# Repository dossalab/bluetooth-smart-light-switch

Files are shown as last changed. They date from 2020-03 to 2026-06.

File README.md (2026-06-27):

# Bluetooth controlled cord light switch

**Before building, read this carefully (especially Safety guidelines)**

This project aims to create a remote-controlled, *smart* cord light switch. It has both physical control button and Bluetooth LE capabilities, allowing for a very natural user experience.

This repo contains both PCB design and firmware.

Hardware seems to work, but has barely been tested in the field. The high voltage part is rated at 220-230V / 50 Hz (European-ish standard). It should be trivial to recalculate the supply for the US standard.

The firmware was never fully developed, but `firmware` directory contains the current work-in-progress state to get you started.

**Make sure you know what you're doing. This project involves working with high voltages and requires advanced electronics experience. I'm not taking any responsibility for any damage arising from use of this device**

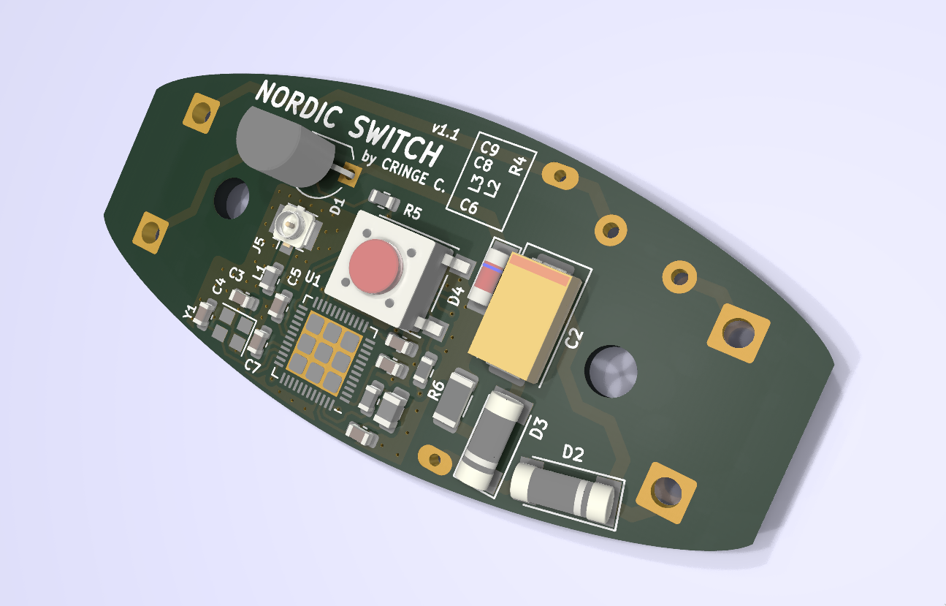
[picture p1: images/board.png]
board render


## Bringup

There are 4 solder pads underneath the board. You'll have to solder some wires to them in order to connect to the programming probe. Supply your own safe external power from your debugging probe or any other low-power source. **NEVER INTERFACE WITH THE DEVICE WHILE PLUGGED INTO MAINS POWER!**

The firmware is written in Rust and uses Embassy, the async framework with nrf-softdevice crate for BLE.

## Some safety guidelines

- Never touch any parts of the board while operational - you'd likely get a shock;
- Don't leave the device unattended for now - it's not stable enough to trust;
- Be in a good state of mind and pay attention to what you are doing - **it is easy to make mistakes and burn your stuff**

## Roadmap

- Proper case design (I just used one from the real switch, with drilled-out insides);
- HomeAssistant integration.

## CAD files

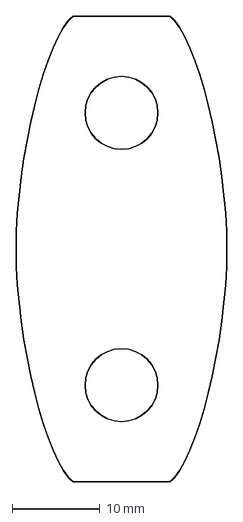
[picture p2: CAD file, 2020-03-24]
board/case-board-outline.dxf
24.0 x 53.0 mm

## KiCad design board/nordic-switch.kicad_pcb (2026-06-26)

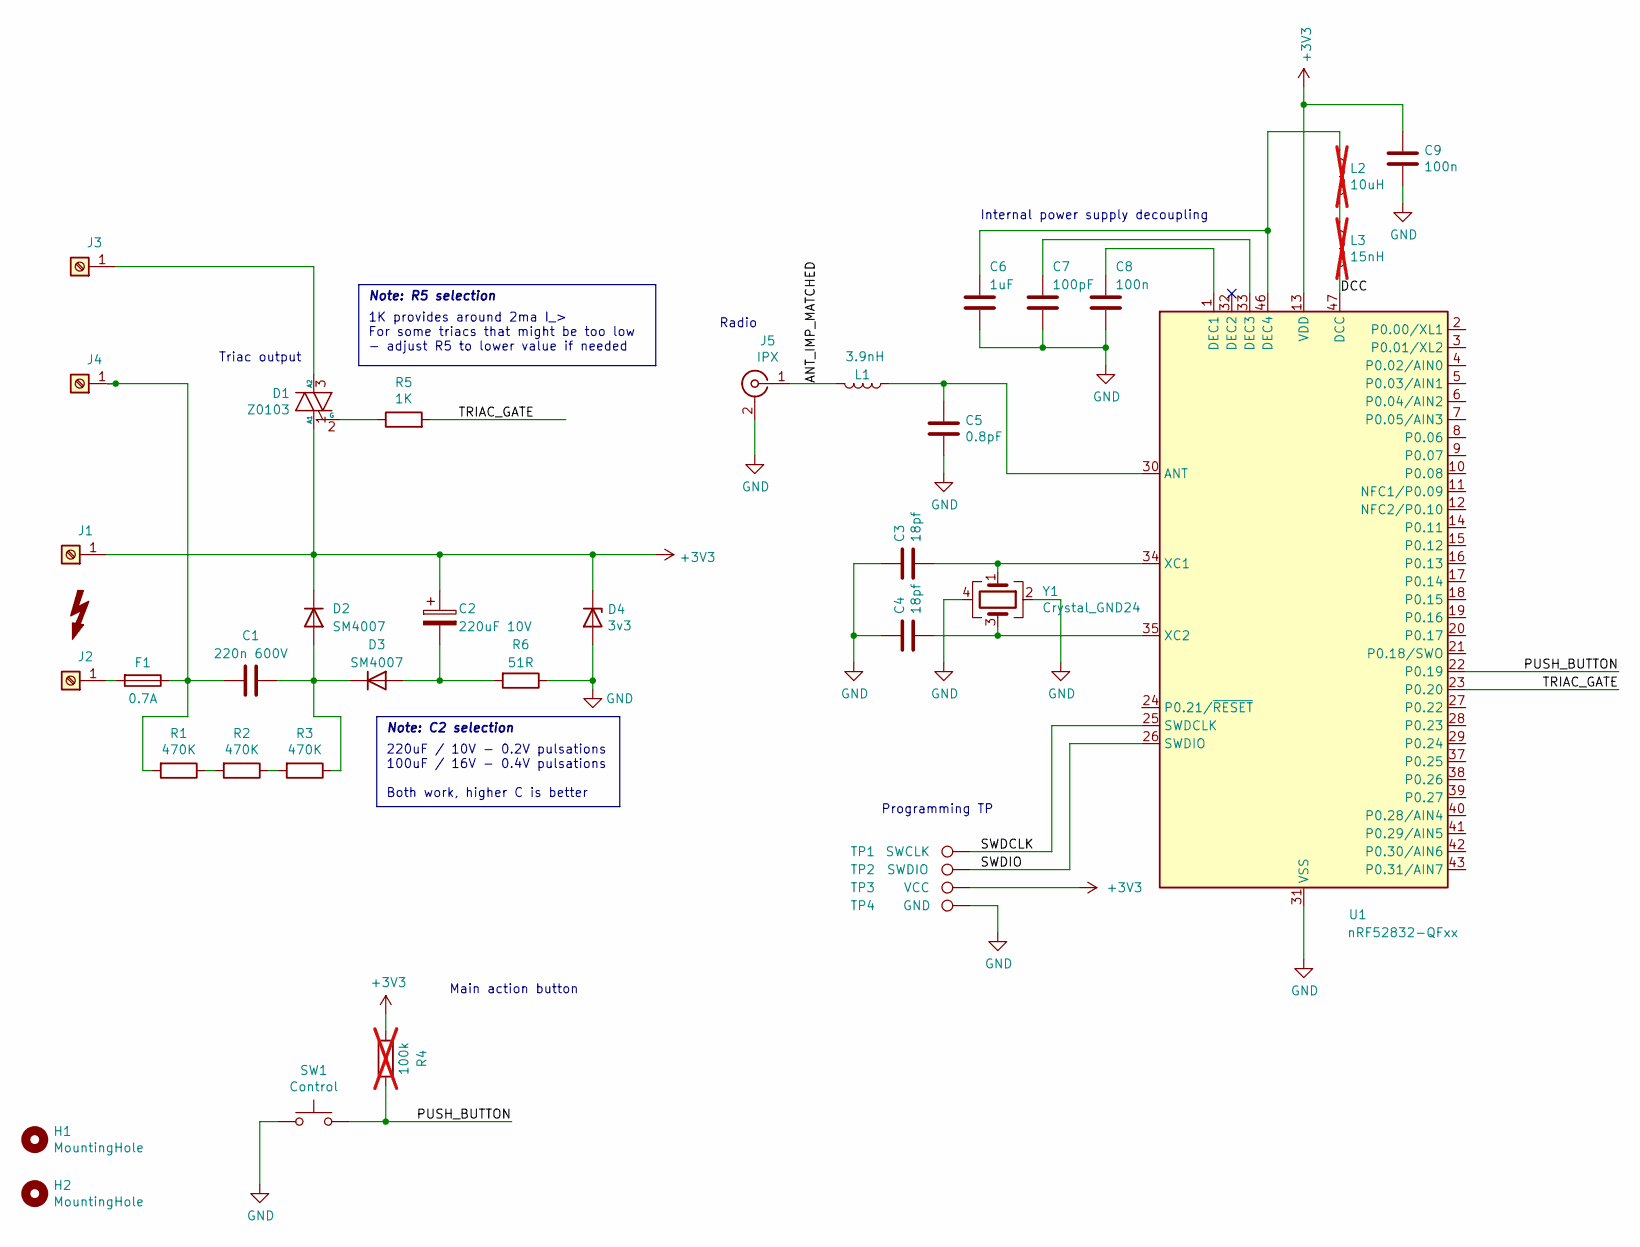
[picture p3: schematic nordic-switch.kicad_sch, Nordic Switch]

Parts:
C1: 220n 600V; CP_CBB_684J_400V_Flat
C2: 220uF 10V; CP_EIA-7343-30_AVX-N
C3, C4: 18pf; C_0603_1608Metric
C5: 0.8pF; C_0603_1608Metric
C6: 1uF; C_0603_1608Metric
C7: 100pF; C_0603_1608Metric
C8, C9: 100n; C_0603_1608Metric
D1: Z0103; TO-92_Inline_Wide
D2, D3: SM4007; D_MELF
D4: 3v3; D_MiniMELF
F1: 0.7A; Fuse_Littelfuse_395Series
H1, H2: MountingHole; MountingHole_3.2mm_M3
J1, J2, J3, J4: Screw_Terminal_01x01; SolderWire-1sqmm_1x01_D1.4mm_OD2.7mm
J5: IPX; U.FL_Hirose_U.FL-R-SMT-1_Vertical
L1: 3.9nH; L_0603_1608Metric
L2: 10uH; L_0805_2012Metric; not fitted
L3: 15nH; L_0603_1608Metric; not fitted
R1, R2, R3: 470K; R_1206_3216Metric
R4: 100k; R_0603_1608Metric; not fitted
R5: 1K; R_0603_1608Metric
R6: 51R; R_1206_3216Metric
SW1: Control; SW_SPST_PTS645
TP1: SWCLK; TestPoint_Pad_D1.0mm
TP2: SWDIO; TestPoint_Pad_D1.0mm
TP3: VCC; TestPoint_Pad_D1.0mm
TP4: GND; TestPoint_Pad_D1.0mm
U1: nRF52832-QFxx; QFN-48-1EP_6x6mm_P0.4mm_EP4.6x4.6mm
Y1: Crystal_GND24; Crystal_SMD_2520-4Pin_2.5x2.0mm

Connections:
+3V3: C2.1, C9.1, D1.1 (A1), D2.1 (K), D4.1 (K), J1.1, R4.2, TP3.1, U1.13 (VDD), U1.36 (VDD), U1.48 (VDD)
/ANT_IMP_MATCHED: J5.1 (In), L1.2
/DCC: L3.2, U1.47 (DCC)
/PUSH_BUTTON: R4.1, SW1.2, U1.22 (P0.19)
/SWDCLK: TP1.1, U1.25 (SWDCLK)
/SWDIO: TP2.1, U1.26 (SWDIO)
/TRIAC_GATE: R5.2, U1.23 (P0.20)
GND: C3.1, C4.1, C5.2, C6.2, C7.2, C8.2, C9.2, D4.2 (A), J5.2 (Ext), R6.1, SW1.1, TP4.1, U1.31 (VSS), U1.45 (VSS), U1.49 (VSS), Y1.2, Y1.4
unnamed: D1.3 (A2), J3.1
unnamed: D1.2 (G), R5.1
unnamed: C1.2, D2.2 (A), D3.1 (K), R3.1
unnamed: C2.2, D3.2 (A), R6.2
unnamed: F1.2, J2.1
unnamed: C1.1, F1.1, J4.1, R1.2
unnamed: L2.2, L3.1
unnamed: R1.1, R2.2
unnamed: R2.1, R3.2
unnamed: C5.1, L1.1, U1.30 (ANT)
unnamed: C8.1, U1.1 (DEC1)
unnamed: C7.1, U1.33 (DEC3)
unnamed: C6.1, L2.1, U1.46 (DEC4)
unnamed: C3.2, U1.34 (XC1), Y1.1
unnamed: C4.2, U1.35 (XC2), Y1.3

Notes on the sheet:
Triac output
Programming TP
Internal power supply decoupling
1K provides around 2ma I_{gt} For some triacs that might be too low - adjust R5 to lower value if needed
Main action button
Note: R5 selection
Note: C2 selection
Radio
220uF / 10V - 0.2V pulsations 100uF / 16V - 0.4V pulsations Both work, higher C is better

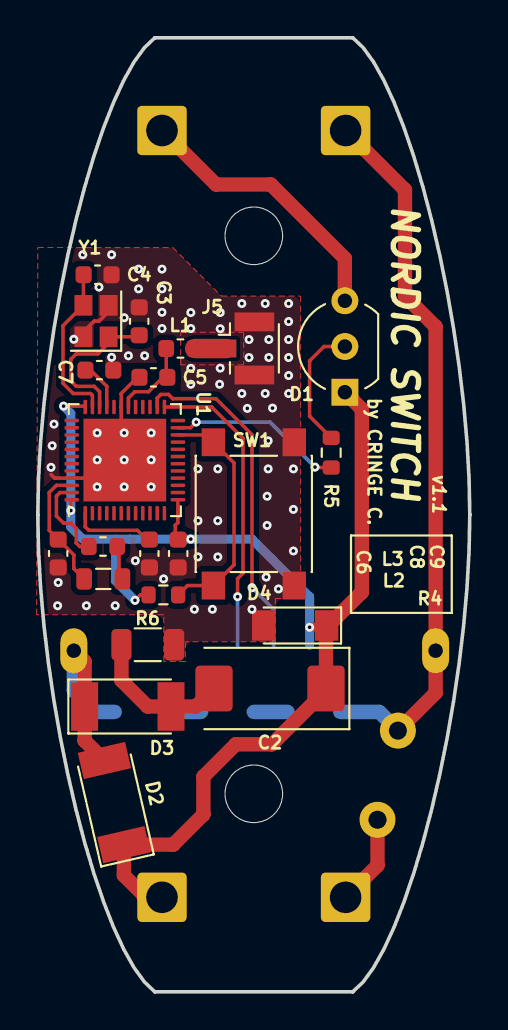
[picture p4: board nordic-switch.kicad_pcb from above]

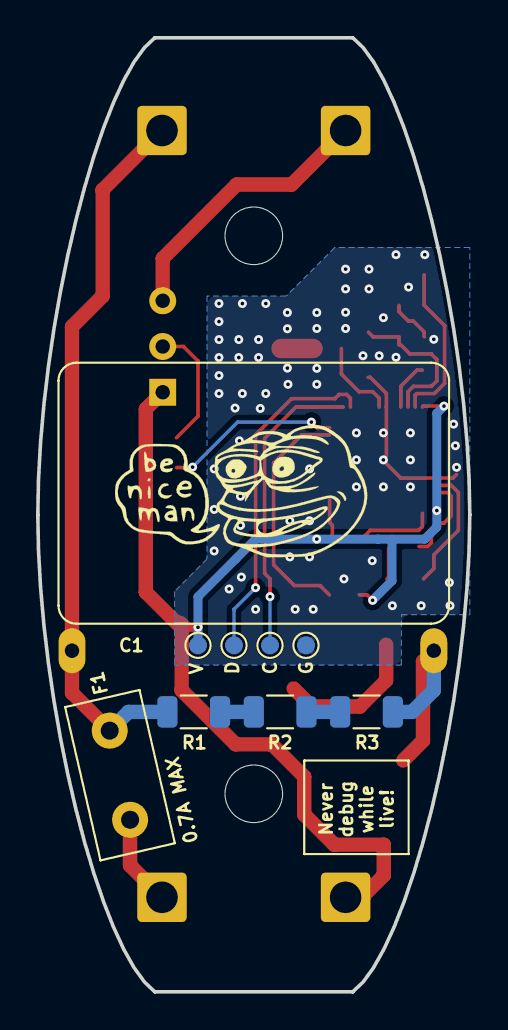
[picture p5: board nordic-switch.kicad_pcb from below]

Board: 2 copper layers, 24.0 x 53.0 mm, 37 parts (9 on the bottom side), 23 nets.

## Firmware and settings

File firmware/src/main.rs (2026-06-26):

//! A part of Nordic switch - Bluetooth controlled cord light switch project
//! This firmware and hardware is a work in progress - use at your own risk.

#![no_std]
#![no_main]

use assign_resources::assign_resources;
use defmt::{info, unwrap};
use embassy_nrf::peripherals;
use embassy_sync::{blocking_mutex::raw::CriticalSectionRawMutex, signal::Signal};
use embassy_time::Timer;
use futures::future;
use git_version::git_version;
use heapless::String;

use embassy_nrf::{
    gpio::{self, Input},
    interrupt, Peripherals,
};
use nrf_softdevice::{
    ble::{self, advertisement_builder as advb, peripheral as blep},
    raw as nrf_defines, Softdevice,
};

use defmt_rtt as _;
use panic_probe as _;

// There are only 2 'resources' - still, good for consistency across projects :)
assign_resources! {
    button: ButtonResources {
        pin: P0_19,
    },
    triac: TriacResources {
        pin: P0_20,
    }
}

/// Actions used for triac control channel
#[derive(defmt::Format)]
enum TriacAction {
    On,
    Off,
    Toggle,
}

/// Channel used to send messages to triac
type TriacSignal = Signal<CriticalSectionRawMutex, TriacAction>;

/// Gatt configuration. A single 'custom' control service containing everything needed.
#[nrf_softdevice::gatt_service(uuid = "c831c2f2-817f-11ee-b962-0242ac120002")]
pub struct ControlService {
    /// Control point that controls the lamp
    #[characteristic(uuid = "c831c2f2-817f-11ee-b962-0242ac130002", read, write)]
    triac_control: bool,

    /// Version string of this firmware for debugging
    #[characteristic(uuid = "c831c2f2-817f-11ee-b962-0242ac140002", read)]
    version: String<32>,
}

/// A gatt server that holds all of our characteristics
#[nrf_softdevice::gatt_server]
pub struct GattServer {
    control: ControlService,
}

/// Runs advertisement cycle. Returns connection that we can feed to the gatt_server.
async fn advertise(softdevice: &Softdevice) -> Result<ble::Connection, blep::AdvertiseError> {
    static ADV_DATA: advb::LegacyAdvertisementPayload = advb::LegacyAdvertisementBuilder::new()
        .flags(&[advb::Flag::GeneralDiscovery, advb::Flag::LE_Only])
        .full_name("Nordic Switch")
        .build();

    static SCAN_DATA: advb::LegacyAdvertisementPayload =
        advb::LegacyAdvertisementBuilder::new().build();

    let packet = blep::ConnectableAdvertisement::ScannableUndirected {
        adv_data: &ADV_DATA,
        scan_data: &SCAN_DATA,
    };

    let config = blep::Config {
        interval: 1600, // 1s
        ..Default::default()
    };

    blep::advertise_connectable(softdevice, packet, &config).await
}

/// Task that handles all the bluetooth stuff
#[embassy_executor::task]
async fn bluetooth_task_run(softdevice: &'static mut Softdevice, triac: &'static TriacSignal) {
    let gatt = unwrap!(GattServer::new(softdevice));

    // Store the git version in the control service to help debug issues in the field
    unwrap!(gatt
        .control
        .version_set(&unwrap!(git_version!().try_into())));

    // That's how we handle all events coming from the gatt_server
    let event_handler = |e: GattServerEvent| match e {
        GattServerEvent::Control(event) => match event {
            ControlServiceEvent::TriacControlWrite(on) => triac.signal(if on {
                TriacAction::On
            } else {
                TriacAction::Off
            }),
        },
    };

    future::join(
        // Run connection cycle
        async {
            loop {
                if let Ok(connection) = advertise(softdevice).await {
                    ble::gatt_server::run(&connection, &gatt, event_handler).await;
                }
            }
        },
        // Run softdevice logic
        softdevice.run(),
    )
    .await;
}

/// Task that listens for triac signals and reacts appropriately
#[embassy_executor::task]
async fn triac_controller_run(res: TriacResources, signal: &'static TriacSignal) {
    // note logic level inversion here - we start with high level
    let mut triac = gpio::Output::new(res.pin, gpio::Level::High, gpio::OutputDrive::Standard);

    loop {
        let action = signal.wait().await;
        info!("received triac action '{}'", action);
        match action {
            TriacAction::On => triac.set_low(),
            TriacAction::Off => triac.set_high(),
            TriacAction::Toggle => triac.toggle(),
        }
    }
}

/// Task that handles button events and sends actions to triac task
#[embassy_executor::task]
async fn button_listener_run(res: ButtonResources, triac: &'static TriacSignal) {
    let mut button = Input::new(res.pin, gpio::Pull::Up);

    loop {
        button.wait_for_falling_edge().await;

        // do a second probe for debouncing
        Timer::after_millis(10).await;
        if button.is_low() {
            triac.signal(TriacAction::Toggle);
        }

        Timer::after_millis(20).await;
    }
}

/// Initializes embassy for NRF52.
fn init_embassy() -> Peripherals {
    let mut config = embassy_nrf::config::Config::default();

    // Softdevice implicitly utilizes the highest-level interrupt priority
    // We have to move all other interrupts to lower priority, unless
    // random issues and asserts from the Softdevice may (and will) occur

    config.gpiote_interrupt_priority = interrupt::Priority::P2;
    config.time_interrupt_priority = interrupt::Priority::P2;

    embassy_nrf::init(config)
}

/// Initializes SoftDevice
fn init_softdevice() -> &'static mut Softdevice {
    let config = nrf_softdevice::Config {
        // The board is lacking LF crystal because of the space restrictions.
        // Switch to internal RC source for now
        clock: Some(nrf_defines::nrf_clock_lf_cfg_t {
            source: nrf_defines::NRF_CLOCK_LF_SRC_RC as u8,
            rc_ctiv: 16,
            rc_temp_ctiv: 2,
            accuracy: nrf_defines::NRF_CLOCK_LF_ACCURACY_500_PPM as u8,
        }),
        ..Default::default()
    };

    Softdevice::enable(&config)
}

// Main task
#[embassy_executor::main]
async fn main(spawner: embassy_executor::Spawner) {
    let p = init_embassy();
    let r = split_resources!(p);

    let softdevice = init_softdevice();
    static TRIAC_SIGNAL: TriacSignal = TriacSignal::new();

    unwrap!(spawner.spawn(bluetooth_task_run(softdevice, &TRIAC_SIGNAL)));
    unwrap!(spawner.spawn(triac_controller_run(r.triac, &TRIAC_SIGNAL)));
    unwrap!(spawner.spawn(button_listener_run(r.button, &TRIAC_SIGNAL)));
}

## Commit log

2020-03-24 Init commit
    [case-board-outline.dxf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]
2024-10-03 update .gitignore for Kicad 6
2024-10-03 PCB version 1.1
    - Switched to Kicad 8
    - Better spacing for the high-voltage part
    - Re-route SWD from crystal area
    [nordic-switch-B_Cu.gbr, nordic-switch-B_Mask.gbr, nordic-switch-B_Paste.gbr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]
2024-10-03 drop gerbers, docs, archives...
    [nordic-switch-B_Cu.gbr, nordic-switch-B_Mask.gbr, nordic-switch-B_Paste.gbr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]
2024-10-03 add sample firmware
